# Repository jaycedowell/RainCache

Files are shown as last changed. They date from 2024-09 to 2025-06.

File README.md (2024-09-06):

# RainCache

## Parts List
 * Arduino Nano ESP32
 * Adafruit Universal USB / DC / Solar Lithium Ion/Polymer charger - bq24074
 * Adafruit MAX17048 LiPoly / LiIon Fuel Gauge and Battery Monitor
 * DFRobot Waterproof Ultrasonic Distance Sensor with Separate Probe (20~600cm)
 * Xain-USA: 3.7V 4400mAh, Li-ion rechargeable Battery Pack
 * Solar panel charger, 3W 6V
 * Norwesco 44405 1175 gallon Low Profile Underground Water Tank - x4
 * 3" PVC cap
 * 3" to 1 1/2" PVC reducer

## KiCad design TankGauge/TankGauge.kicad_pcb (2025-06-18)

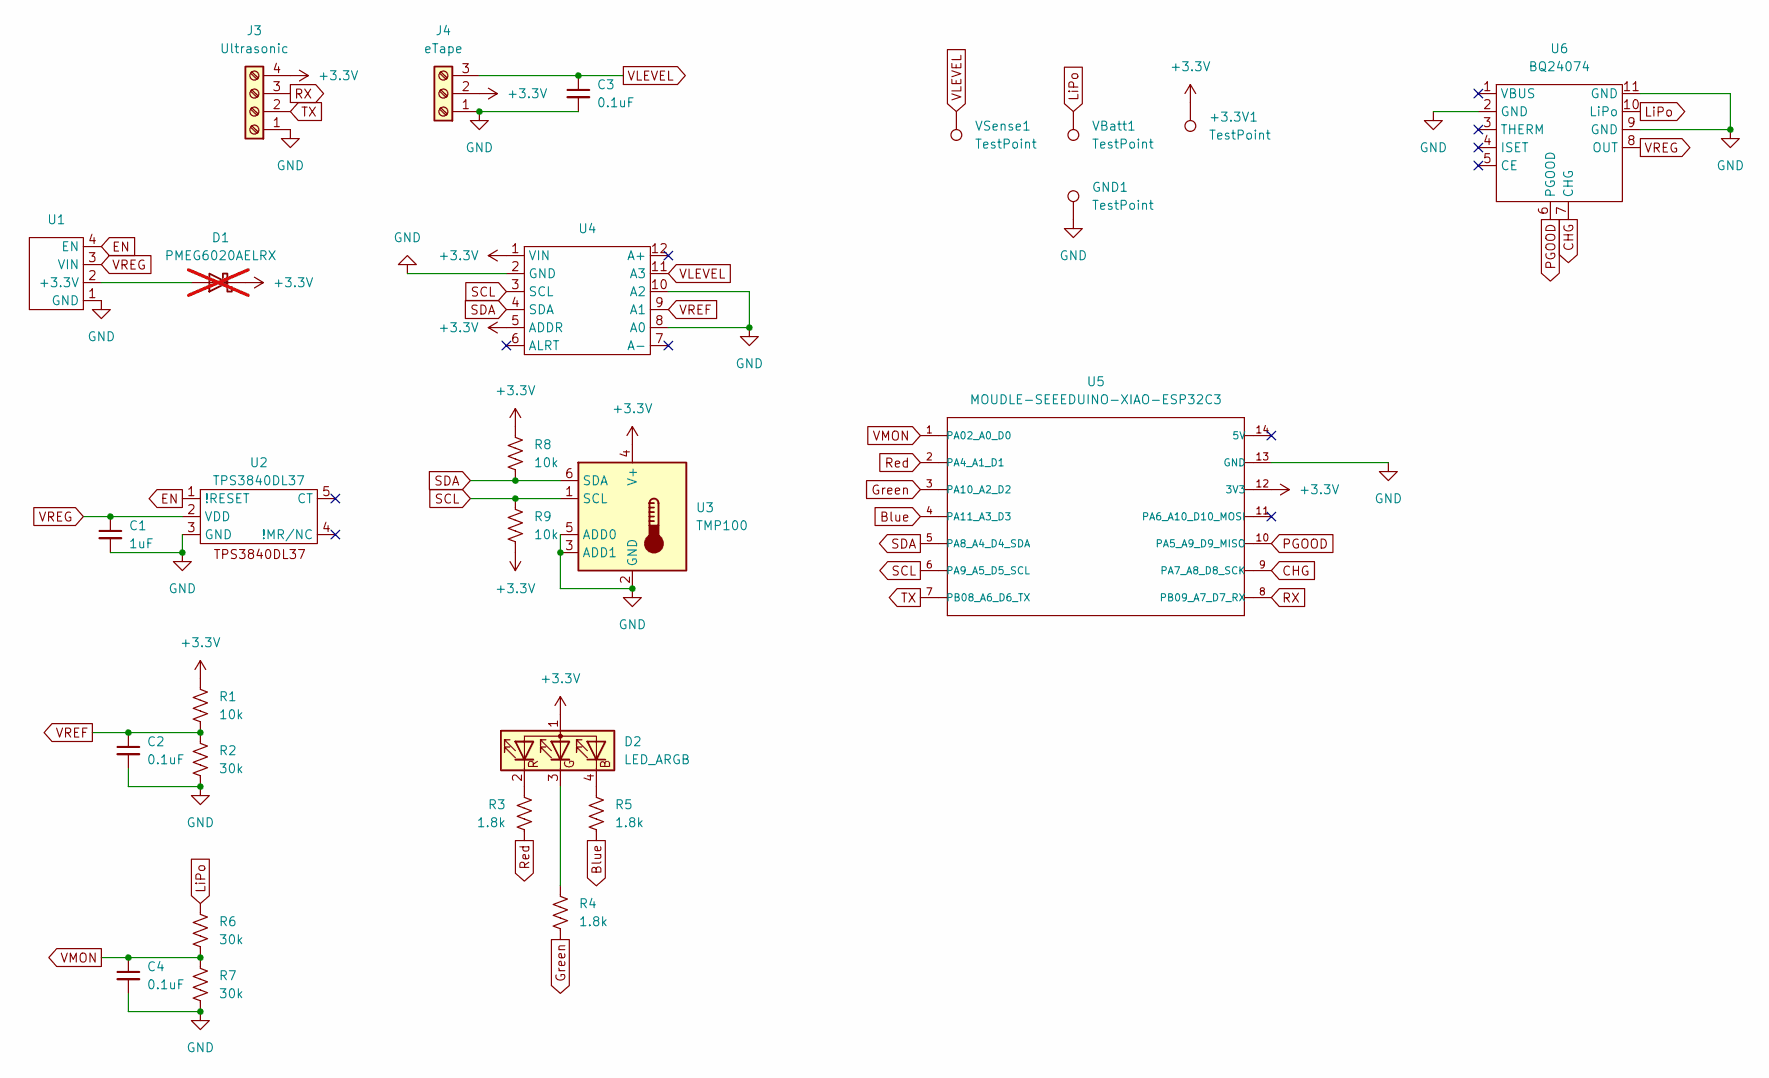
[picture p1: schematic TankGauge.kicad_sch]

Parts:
+3.3V1: TestPoint; TestPoint_Pad_D2.0mm
C1: 1uF; C_0805_2012Metric_Pad1.18x1.45mm_HandSolder
C2, C3, C4: 0.1uF; C_0805_2012Metric_Pad1.18x1.45mm_HandSolder
D1: PMEG6020AELRX; Nexperia_CFP3_SOD-123W; not fitted
D2: LED_ARGB; LED_Kingbright_AAA3528ESGCT
GND1: TestPoint; TestPoint_Pad_D2.0mm
J3: Ultrasonic; PinHeader_1x04_P2.54mm_Vertical
J4: eTape; PinHeader_1x03_P2.54mm_Vertical
R1, R8, R9: 10k; R_0805_2012Metric_Pad1.20x1.40mm_HandSolder
R2, R6, R7: 30k; R_0805_2012Metric_Pad1.20x1.40mm_HandSolder
R3, R4, R5: 1.8k; R_0805_2012Metric_Pad1.20x1.40mm_HandSolder
U1: TLV62569; TLV62569 Breakout Board
U2: TPS3840DL37; SOT-23-5_HandSoldering
U3: TMP100; SOT-23-6
U4: ADS1115 Breakout Board
U5: MOUDLE-SEEEDUINO-XIAO-ESP32C3; XIAO-ESP32C3
U6: BQ24074; PinHeader_1x11_P2.54mm_Vertical
VBatt1: TestPoint; TestPoint_Pad_D2.0mm
VSense1: TestPoint; TestPoint_Pad_D2.0mm

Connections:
+3.3V: +3.3V1.1, D1.1 (K), D2.1 (A), J3.4, J4.2, R1.1, R8.1, R9.2, U3.4 (V+), U4.1 (VIN), U4.5 (ADDR), U5.12 (3V3)
Blue: R5.2, U5.4 (PA11_A3_D3)
CHG: U5.9 (PA7_A8_D8_SCK), U6.7 (CHG)
EN: U1.4 (EN), U2.1 (!RESET)
GND: C1.2, C2.2, C3.2, C4.2, GND1.1, J3.1, J4.1, R2.2, R7.2, U1.1 (GND), U2.3 (GND), U3.2 (GND), U3.3 (ADD1), U3.5 (ADD0), U4.2 (GND), U4.8 (A0), U4.10 (A2), U5.13 (GND), U6.2 (GND), U6.9 (GND), U6.11 (GND)
Green: R4.2, U5.3 (PA10_A2_D2)
LiPo: R6.1, U6.10 (LiPo), VBatt1.1
unnamed: D1.2 (A), U1.2 (+3.3V)
unnamed: D2.4 (BK), R5.1
unnamed: D2.3 (GK), R4.1
unnamed: D2.2 (RK), R3.1
PGOOD: U5.10 (PA5_A9_D9_MISO), U6.6 (PGOOD)
RX: J3.3, U5.8 (PB09_A7_D7_RX)
Red: R3.2, U5.2 (PA4_A1_D1)
SCL: R9.1, U3.1 (SCL), U4.3 (SCL), U5.6 (PA9_A5_D5_SCL)
SDA: R8.2, U3.6 (SDA), U4.4 (SDA), U5.5 (PA8_A4_D4_SDA)
TX: J3.2, U5.7 (PB08_A6_D6_TX)
VLEVEL: C3.1, J4.3, U4.11 (A3), VSense1.1
VMON: C4.1, R6.2, R7.1, U5.1 (PA02_A0_D0)
VREF: C2.1, R1.2, R2.1, U4.9 (A1)
VREG: C1.1, U1.3 (VIN), U2.2 (VDD), U6.8 (OUT)

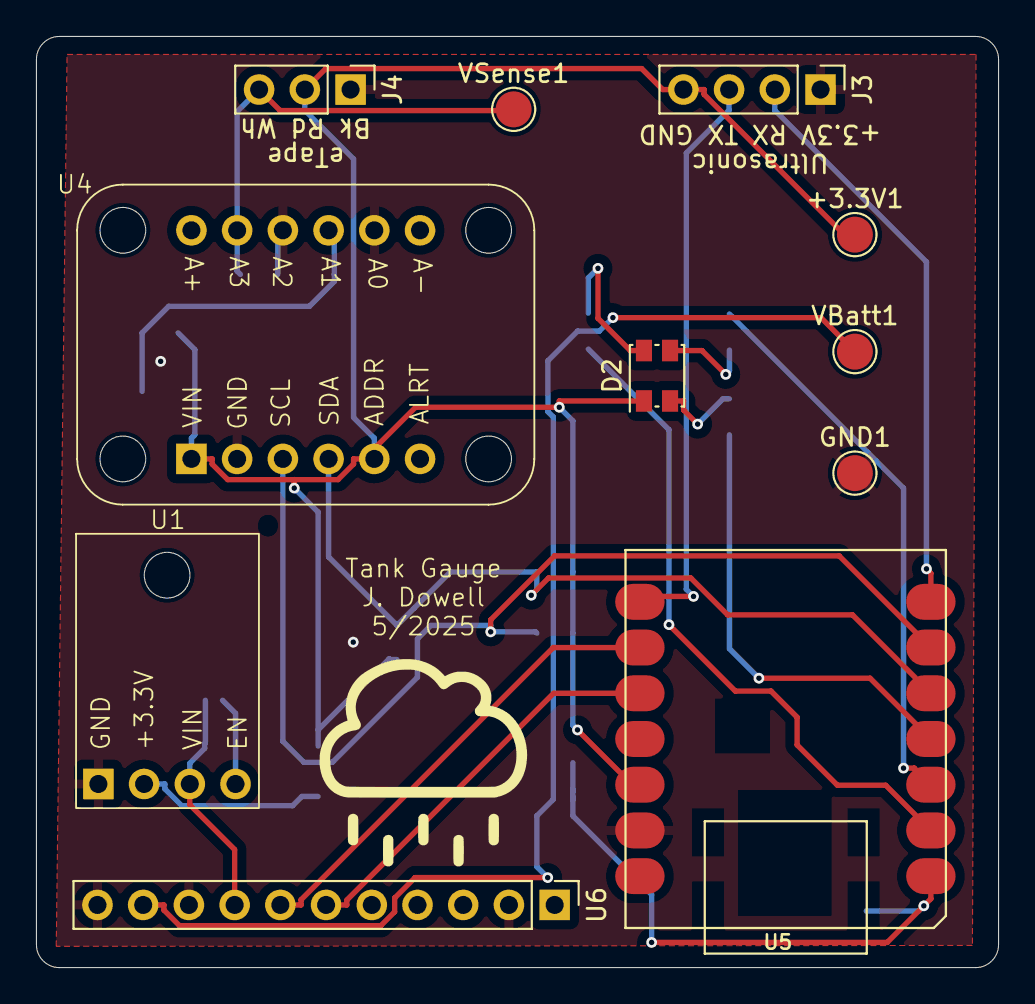
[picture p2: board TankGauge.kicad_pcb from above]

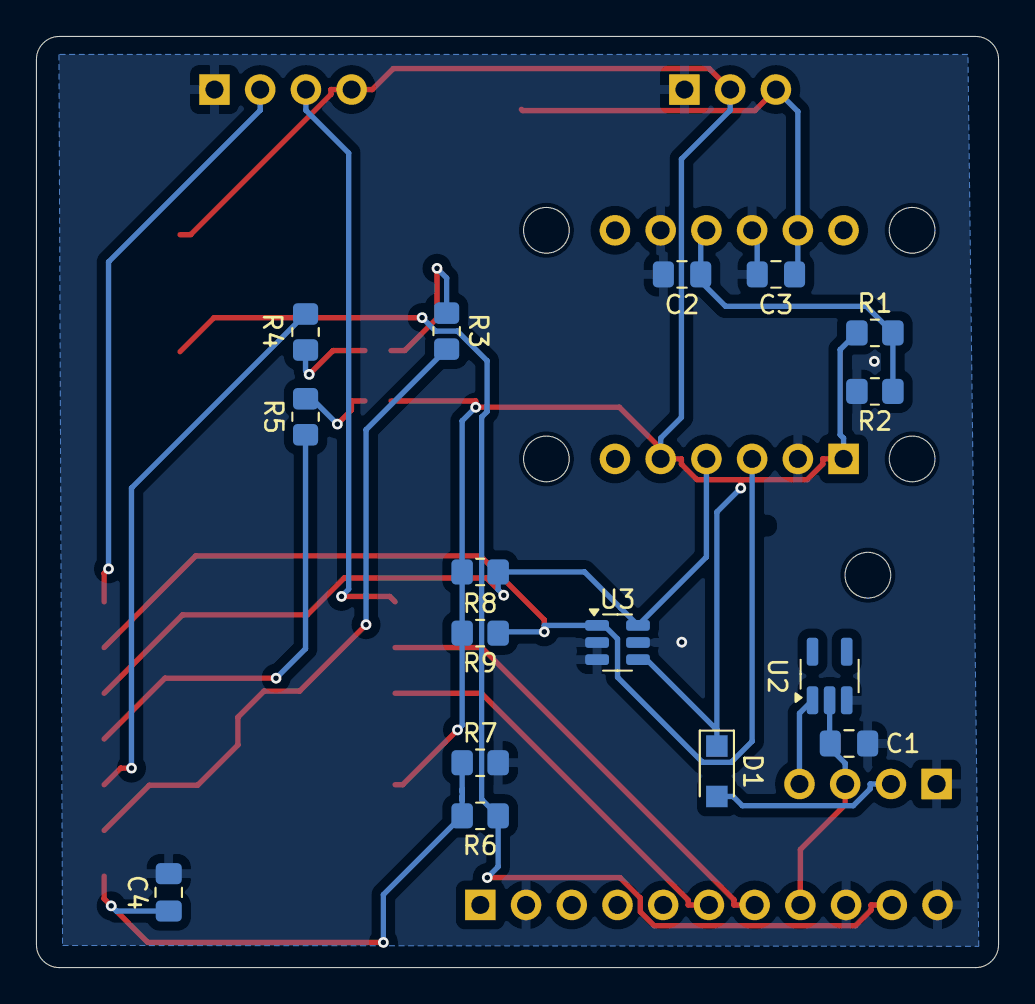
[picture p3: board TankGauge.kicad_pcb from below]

Board: 2 copper layers, 53.5 x 51.7 mm, 28 parts (16 on the bottom side), 21 nets.

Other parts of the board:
G1: LOGO; RainCache

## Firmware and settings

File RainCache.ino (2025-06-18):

#include <WiFi.h>
#include <ESP32Time.h>
#include <math.h>
#include <Wire.h>
#include "driver/temperature_sensor.h"
#include <Adafruit_ADS1X15.h>
#include "TMP100.h"

#include "WiFi_private.h"
/* WiFi_private.h includes:
    * ssid, pass - WiFi setup
    * staticIP, subnet - static IP address and network submask
    * gateway - gateway address
    * primaryDNS, secondaryDNS - DNS servers
*/

temperature_sensor_handle_t temp_sensor = NULL;
temperature_sensor_config_t temp_sensor_config = TEMPERATURE_SENSOR_CONFIG_DEFAULT(-10, 80);

WiFiServer server(80);

ESP32Time rtc(0);
unsigned long lastNTPSync = 0;

Adafruit_ADS1115 ads1115;
TMP100 tmp100;

byte icon_raw[] = {0, 0, 1, 0, 1, 0, 32, 32, 0, 0, 1, 0, 32, 0, 168, 16, 0, 0, 22, 0, 0, 0, 40, 0, 0, 0, 32, 0, 0, 0, 64, 0, 0, 0, 1, 0, 32, 0, 0, 0, 0, 0, 128, 16, 0, 0, 0, 0, 0, 0, 0, 0, 0, 0, 0, 0, 0, 0, 0, 0, 0, 0, 0, 0, 0, 0, 0, 0, 0, 0, 0, 0, 0, 0, 0, 0, 0, 0, 0, 0, 0, 0, 0, 0, 0, 0, 0, 0, 0, 0, 0, 0, 0, 0, 0, 0, 0, 0, 0, 0, 0, 0, 0, 0, 0, 0, 0, 0, 0, 0, 0, 0, 0, 0, 0, 0, 0, 0, 0, 0, 0, 0, 0, 0, 0, 0, 0, 0, 0, 0, 0, 0, 0, 0, 0, 0, 0, 0, 0, 0, 0, 0, 0, 0, 0, 0, 0, 0, 0, 0, 0, 0, 0, 0, 0, 0, 0, 0, 0, 0, 0, 0, 0, 0, 0, 0, 0, 0, 0, 0, 0, 0, 0, 0, 0, 0, 0, 0, 0, 0, 0, 0, 0, 0, 0, 0, 0, 0, 0, 0, 0, 0, 0, 0, 0, 0, 0, 0, 0, 0, 0, 0, 0, 0, 0, 0, 0, 0, 0, 0, 0, 0, 0, 0, 0, 0, 0, 0, 0, 0, 0, 0, 0, 0, 0, 0, 0, 0, 0, 0, 0, 0, 0, 0, 0, 0, 0, 0, 0, 0, 0, 0, 0, 0, 0, 0, 0, 0, 0, 0, 0, 0, 0, 0, 0, 0, 0, 0, 0, 0, 0, 0, 0, 0, 0, 0, 0, 0, 0, 0, 0, 0, 0, 0, 0, 0, 0, 0, 0, 0, 0, 0, 0, 0, 0, 0, 0, 0, 0, 0, 0, 0, 0, 0, 0, 0, 0, 0, 0, 0, 0, 0, 0, 0, 0, 0, 0, 0, 0, 0, 0, 0, 0, 0, 0, 0, 0, 0, 0, 0, 0, 0, 0, 0, 0, 0, 0, 0, 0, 0, 0, 0, 0, 0, 0, 0, 0, 0, 0, 0, 0, 0, 0, 0, 0, 0, 0, 0, 0, 0, 0, 0, 0, 0, 0, 0, 0, 0, 0, 0, 0, 0, 3, 0, 0, 77, 3, 0, 0, 77, 0, 0, 0, 0, 0, 0, 0, 0, 0, 0, 0, 0, 0, 0, 0, 0, 0, 0, 0, 0, 0, 0, 0, 0, 3, 0, 0, 77, 3, 0, 0, 77, 0, 0, 0, 0, 0, 0, 0, 0, 0, 0, 0, 0, 0, 0, 0, 0, 0, 0, 0, 0, 0, 0, 0, 0, 0, 0, 0, 0, 0, 0, 0, 0, 0, 0, 0, 0, 0, 0, 0, 0, 0, 0, 0, 0, 0, 0, 0, 0, 0, 0, 0, 0, 0, 0, 0, 0, 0, 0, 0, 0, 0, 0, 0, 0, 0, 0, 0, 0, 0, 0, 0, 0, 0, 0, 0, 0, 0, 0, 0, 0, 0, 0, 0, 0, 0, 0, 0, 0, 3, 0, 2, 248, 3, 0, 2, 249, 0, 0, 0, 0, 0, 0, 0, 0, 0, 0, 0, 0, 0, 0, 0, 0, 0, 0, 0, 0, 0, 0, 0, 0, 3, 0, 2, 248, 3, 0, 2, 249, 0, 0, 0, 0, 0, 0, 0, 0, 0, 0, 0, 0, 0, 0, 0, 0, 0, 0, 0, 0, 0, 0, 0, 0, 0, 0, 0, 0, 0, 0, 0, 0, 0, 0, 0, 0, 0, 0, 0, 0, 0, 0, 0, 0, 0, 0, 0, 0, 0, 0, 0, 0, 0, 0, 0, 0, 0, 0, 0, 0, 0, 0, 0, 0, 0, 0, 0, 0, 0, 0, 0, 0, 3, 0, 0, 77, 3, 0, 0, 77, 0, 0, 0, 0, 0, 0, 0, 0, 4, 1, 3, 255, 4, 1, 3, 255, 0, 0, 0, 0, 0, 0, 0, 0, 3, 0, 0, 77, 3, 0, 0, 77, 0, 0, 0, 0, 0, 0, 0, 0, 4, 1, 3, 255, 4, 1, 3, 255, 0, 0, 0, 0, 0, 0, 0, 0, 3, 0, 0, 77, 3, 0, 0, 77, 0, 0, 0, 0, 0, 0, 0, 0, 0, 0, 0, 0, 0, 0, 0, 0, 0, 0, 0, 0, 0, 0, 0, 0, 0, 0, 0, 0, 0, 0, 0, 0, 0, 0, 0, 0, 0, 0, 0, 0, 0, 0, 0, 0, 0, 0, 0, 0, 0, 0, 0, 0, 0, 0, 0, 0, 3, 0, 2, 248, 3, 0, 2, 249, 0, 0, 0, 0, 0, 0, 0, 0, 3, 0, 2, 248, 3, 0, 2, 248, 0, 0, 0, 0, 0, 0, 0, 0, 3, 0, 2, 248, 3, 0, 2, 249, 0, 0, 0, 0, 0, 0, 0, 0, 3, 0, 2, 248, 3, 0, 2, 248, 0, 0, 0, 0, 0, 0, 0, 0, 3, 0, 2, 248, 3, 0, 2, 249, 0, 0, 0, 0, 0, 0, 0, 0, 0, 0, 0, 0, 0, 0, 0, 0, 0, 0, 0, 0, 0, 0, 0, 0, 0, 0, 0, 0, 0, 0, 0, 0, 0, 0, 0, 0, 0, 0, 0, 0, 0, 0, 0, 0, 0, 0, 0, 0, 0, 0, 0, 0, 0, 0, 0, 0, 4, 1, 3, 255, 4, 1, 3, 255, 0, 0, 0, 0, 0, 0, 0, 0, 3, 0, 0, 77, 3, 0, 0, 77, 0, 0, 0, 0, 0, 0, 0, 0, 4, 1, 3, 255, 4, 1, 3, 255, 0, 0, 0, 0, 0, 0, 0, 0, 3, 0, 0, 77, 3, 0, 0, 77, 0, 0, 0, 0, 0, 0, 0, 0, 4, 1, 3, 255, 4, 1, 3, 255, 0, 0, 0, 0, 0, 0, 0, 0, 0, 0, 0, 0, 0, 0, 0, 0, 0, 0, 0, 0, 0, 0, 0, 0, 0, 0, 0, 0, 0, 0, 0, 0, 0, 0, 0, 0, 0, 0, 0, 0, 0, 0, 0, 0, 0, 0, 0, 0, 0, 0, 0, 0, 0, 0, 0, 0, 3, 0, 2, 248, 3, 0, 2, 248, 0, 0, 0, 0, 0, 0, 0, 0, 0, 0, 0, 0, 0, 0, 0, 0, 0, 0, 0, 0, 0, 0, 0, 0, 3, 0, 2, 248, 3, 0, 2, 248, 0, 0, 0, 0, 0, 0, 0, 0, 0, 0, 0, 0, 0, 0, 0, 0, 0, 0, 0, 0, 0, 0, 0, 0, 3, 0, 2, 248, 3, 0, 2, 248, 0, 0, 0, 0, 0, 0, 0, 0, 0, 0, 0, 0, 0, 0, 0, 0, 0, 0, 0, 0, 0, 0, 0, 0, 0, 0, 0, 0, 0, 0, 0, 0, 0, 0, 0, 0, 0, 0, 0, 0, 0, 0, 0, 0, 0, 0, 0, 0, 0, 0, 0, 0, 0, 0, 0, 0, 3, 0, 0, 77, 3, 0, 0, 77, 0, 0, 0, 0, 0, 0, 0, 0, 0, 0, 0, 0, 0, 0, 0, 0, 0, 0, 0, 0, 0, 0, 0, 0, 3, 0, 0, 77, 3, 0, 0, 77, 0, 0, 0, 0, 0, 0, 0, 0, 0, 0, 0, 0, 0, 0, 0, 0, 0, 0, 0, 0, 0, 0, 0, 0, 3, 0, 0, 77, 3, 0, 0, 77, 0, 0, 0, 0, 0, 0, 0, 0, 0, 0, 0, 0, 0, 0, 0, 0, 0, 0, 0, 0, 0, 0, 0, 0, 0, 0, 0, 0, 0, 0, 0, 0, 0, 0, 0, 0, 0, 0, 0, 0, 0, 0, 0, 7, 3, 0, 0, 76, 2, 0, 2, 119, 4, 0, 2, 127, 4, 0, 2, 127, 4, 0, 2, 127, 4, 0, 2, 127, 4, 0, 2, 127, 4, 0, 2, 127, 4, 0, 2, 127, 4, 0, 2, 127, 4, 0, 2, 127, 4, 0, 2, 127, 4, 0, 2, 127, 4, 0, 2, 127, 4, 0, 2, 127, 4, 0, 2, 127, 4, 0, 2, 127, 4, 0, 2, 127, 4, 0, 2, 127, 4, 0, 2, 127, 4, 0, 2, 127, 4, 0, 2, 127, 2, 0, 2, 119, 3, 0, 0, 76, 0, 0, 0, 7, 0, 0, 0, 0, 0, 0, 0, 0, 0, 0, 0, 0, 0, 0, 0, 0, 0, 0, 0, 0, 2, 0, 2, 90, 3, 0, 2, 232, 4, 1, 3, 255, 4, 1, 3, 255, 4, 1, 3, 255, 4, 1, 3, 255, 4, 1, 3, 255, 4, 1, 3, 255, 4, 1, 3, 255, 4, 1, 3, 255, 4, 1, 3, 255, 4, 1, 3, 255, 4, 1, 3, 255, 4, 1, 3, 255, 4, 1, 3, 255, 4, 1, 3, 255, 4, 1, 3, 255, 4, 1, 3, 255, 4, 1, 3, 255, 4, 1, 3, 255, 4, 1, 3, 255, 4, 1, 3, 255, 4, 1, 3, 255, 4, 1, 3, 255, 4, 1, 3, 255, 4, 1, 3, 255, 3, 0, 2, 232, 2, 0, 2, 90, 0, 0, 0, 0, 0, 0, 0, 0, 0, 0, 0, 0, 2, 0, 2, 114, 3, 1, 2, 254, 4, 1, 3, 255, 3, 0, 2, 205, 3, 0, 1, 138, 2, 0, 2, 127, 2, 0, 2, 127, 2, 0, 2, 127, 2, 0, 2, 127, 2, 0, 2, 127, 2, 0, 2, 127, 2, 0, 2, 127, 2, 0, 2, 127, 2, 0, 2, 127, 2, 0, 2, 127, 2, 0, 2, 127, 2, 0, 2, 127, 2, 0, 2, 127, 2, 0, 2, 127, 2, 0, 2, 127, 2, 0, 2, 127, 2, 0, 2, 127, 2, 0, 2, 127, 2, 0, 2, 127, 2, 0, 2, 127, 3, 0, 1, 138, 3, 0, 2, 205, 4, 1, 3, 255, 3, 1, 2, 254, 2, 0, 2, 114, 0, 0, 0, 0, 0, 0, 0, 48, 3, 0, 2, 251, 3, 0, 2, 252, 2, 0, 2, 103, 0, 0, 0, 0, 0, 0, 0, 0, 0, 0, 0, 0, 0, 0, 0, 0, 0, 0, 0, 0, 0, 0, 0, 0, 0, 0, 0, 0, 0, 0, 0, 0, 0, 0, 0, 0, 0, 0, 0, 0, 0, 0, 0, 0, 0, 0, 0, 0, 0, 0, 0, 0, 0, 0, 0, 0, 0, 0, 0, 0, 0, 0, 0, 0, 0, 0, 0, 0, 0, 0, 0, 0, 0, 0, 0, 0, 0, 0, 0, 0, 0, 0, 0, 0, 0, 0, 0, 0, 0, 0, 0, 0, 0, 0, 0, 0, 2, 0, 2, 102, 3, 0, 2, 252, 3, 0, 2, 251, 0, 0, 0, 48, 3, 0, 1, 164, 4, 1, 3, 255, 3, 0, 1, 141, 0, 0, 0, 0, 0, 0, 0, 0, 0, 0, 0, 0, 0, 0, 0, 0, 0, 0, 0, 0, 0, 0, 0, 0, 0, 0, 0, 0, 0, 0, 0, 0, 0, 0, 0, 0, 0, 0, 0, 0, 0, 0, 0, 0, 0, 0, 0, 0, 0, 0, 0, 0, 0, 0, 0, 0, 0, 0, 0, 0, 0, 0, 0, 0, 0, 0, 0, 0, 0, 0, 0, 0, 0, 0, 0, 0, 0, 0, 0, 0, 0, 0, 0, 0, 0, 0, 0, 0, 0, 0, 0, 0, 0, 0, 0, 0, 0, 0, 0, 0, 0, 0, 0, 0, 3, 0, 1, 141, 4, 1, 3, 255, 3, 0, 1, 164, 3, 0, 2, 230, 4, 1, 3, 255, 0, 0, 0, 36, 0, 0, 0, 0, 0, 0, 0, 0, 0, 0, 0, 0, 0, 0, 0, 0, 0, 0, 0, 0, 0, 0, 0, 0, 0, 0, 0, 0, 0, 0, 0, 0, 0, 0, 0, 0, 0, 0, 0, 0, 0, 0, 0, 0, 0, 0, 0, 0, 0, 0, 0, 0, 0, 0, 0, 0, 0, 0, 0, 0, 0, 0, 0, 0, 0, 0, 0, 0, 0, 0, 0, 0, 0, 0, 0, 0, 0, 0, 0, 0, 0, 0, 0, 0, 0, 0, 0, 0, 0, 0, 0, 0, 0, 0, 0, 0, 0, 0, 0, 0, 0, 0, 0, 0, 0, 0, 0, 35, 4, 1, 3, 255, 3, 0, 2, 230, 3, 0, 2, 251, 4, 1, 3, 255, 0, 0, 0, 4, 0, 0, 0, 0, 0, 0, 0, 0, 0, 0, 0, 0, 0, 0, 0, 0, 0, 0, 0, 0, 0, 0, 0, 0, 0, 0, 0, 0, 0, 0, 0, 0, 0, 0, 0, 0, 0, 0, 0, 0, 0, 0, 0, 0, 0, 0, 0, 0, 0, 0, 0, 0, 0, 0, 0, 0, 0, 0, 0, 0, 0, 0, 0, 0, 0, 0, 0, 0, 0, 0, 0, 0, 0, 0, 0, 0, 0, 0, 0, 0, 0, 0, 0, 0, 0, 0, 0, 0, 0, 0, 0, 0, 0, 0, 0, 0, 0, 0, 0, 0, 0, 0, 0, 0, 0, 0, 0, 3, 4, 1, 3, 255, 3, 1, 2, 252, 3, 0, 2, 229, 4, 1, 3, 255, 0, 0, 0, 37, 0, 0, 0, 0, 0, 0, 0, 0, 0, 0, 0, 0, 0, 0, 0, 0, 0, 0, 0, 0, 0, 0, 0, 0, 0, 0, 0, 0, 0, 0, 0, 0, 0, 0, 0, 0, 0, 0, 0, 0, 0, 0, 0, 0, 0, 0, 0, 0, 0, 0, 0, 0, 0, 0, 0, 0, 0, 0, 0, 0, 0, 0, 0, 0, 0, 0, 0, 0, 0, 0, 0, 0, 0, 0, 0, 0, 0, 0, 0, 0, 0, 0, 0, 0, 0, 0, 0, 0, 0, 0, 0, 0, 0, 0, 0, 0, 0, 0, 0, 0, 0, 0, 0, 0, 0, 0, 0, 35, 4, 1, 3, 255, 3, 0, 2, 231, 3, 0, 1, 163, 4, 1, 3, 255, 3, 0, 1, 143, 0, 0, 0, 0, 0, 0, 0, 0, 0, 0, 0, 0, 0, 0, 0, 0, 0, 0, 0, 0, 0, 0, 0, 0, 0, 0, 0, 0, 0, 0, 0, 0, 0, 0, 0, 0, 0, 0, 0, 0, 0, 0, 0, 0, 0, 0, 0, 0, 0, 0, 0, 0, 0, 0, 0, 0, 0, 0, 0, 0, 0, 0, 0, 0, 0, 0, 0, 0, 0, 0, 0, 0, 0, 0, 0, 0, 0, 0, 0, 0, 0, 0, 0, 0, 0, 0, 0, 0, 0, 0, 0, 0, 0, 0, 0, 0, 0, 0, 0, 0, 0, 0, 0, 0, 3, 0, 1, 141, 4, 1, 3, 255, 3, 0, 1, 165, 0, 0, 0, 47, 3, 0, 2, 251, 3, 0, 2, 253, 2, 0, 2, 104, 0, 0, 0, 0, 0, 0, 0, 0, 0, 0, 0, 0, 0, 0, 0, 0, 0, 0, 0, 0, 0, 0, 0, 0, 0, 0, 0, 0, 0, 0, 0, 0, 0, 0, 0, 0, 0, 0, 0, 0, 0, 0, 0, 0, 0, 0, 0, 0, 0, 0, 0, 0, 0, 0, 0, 0, 0, 0, 0, 0, 0, 0, 0, 0, 0, 0, 0, 0, 0, 0, 0, 0, 0, 0, 0, 0, 0, 0, 0, 0, 0, 0, 0, 0, 0, 0, 0, 0, 0, 0, 0, 0, 0, 0, 0, 0, 2, 0, 2, 103, 3, 0, 2, 252, 3, 0, 2, 251, 0, 0, 0, 49, 0, 0, 0, 0, 2, 0, 2, 112, 3, 1, 2, 254, 4, 1, 3, 255, 3, 0, 2, 207, 0, 0, 0, 8, 0, 0, 0, 0, 0, 0, 0, 0, 0, 0, 0, 0, 0, 0, 0, 0, 0, 0, 0, 0, 0, 0, 0, 0, 0, 0, 0, 0, 0, 0, 0, 0, 0, 0, 0, 0, 0, 0, 0, 0, 0, 0, 0, 0, 0, 0, 0, 0, 0, 0, 0, 0, 0, 0, 0, 0, 0, 0, 0, 0, 0, 0, 0, 0, 0, 0, 0, 0, 0, 0, 0, 0, 0, 0, 0, 0, 0, 0, 0, 8, 3, 0, 1, 139, 3, 0, 2, 205, 4, 1, 3, 255, 3, 1, 3, 254, 2, 0, 2, 115, 0, 0, 0, 0, 0, 0, 0, 0, 0, 0, 0, 0, 2, 0, 2, 88, 3, 1, 2, 254, 4, 1, 3, 255, 0, 0, 0, 2, 0, 0, 0, 0, 0, 0, 0, 0, 0, 0, 0, 0, 0, 0, 0, 0, 0, 0, 0, 0, 0, 0, 0, 0, 0, 0, 0, 0, 0, 0, 0, 0, 0, 0, 0, 0, 0, 0, 0, 0, 0, 0, 0, 0, 0, 0, 0, 0, 0, 0, 0, 0, 0, 0, 0, 0, 0, 0, 0, 0, 0, 0, 0, 0, 0, 0, 0, 0, 0, 0, 0, 0, 0, 0, 0, 0, 3, 0, 0, 68, 4, 1, 3, 255, 4, 1, 3, 255, 3, 0, 2, 232, 2, 0, 2, 91, 0, 0, 0, 0, 0, 0, 0, 0, 0, 0, 0, 0, 0, 0, 0, 0, 0, 0, 0, 0, 3, 0, 2, 237, 4, 1, 3, 255, 0, 0, 0, 21, 0, 0, 0, 0, 0, 0, 0, 0, 0, 0, 0, 0, 0, 0, 0, 0, 0, 0, 0, 0, 0, 0, 0, 0, 0, 0, 0, 0, 0, 0, 0, 0, 0, 0, 0, 0, 0, 0, 0, 0, 0, 0, 0, 0, 0, 0, 0, 0, 0, 0, 0, 0, 0, 0, 0, 0, 0, 0, 0, 0, 0, 0, 0, 0, 0, 0, 0, 0, 0, 0, 0, 0, 0, 0, 0, 3, 3, 0, 2, 194, 4, 1, 3, 255, 3, 0, 1, 144, 0, 0, 0, 7, 0, 0, 0, 0, 0, 0, 0, 0, 0, 0, 0, 0, 0, 0, 0, 0, 0, 0, 0, 0, 0, 0, 0, 0, 3, 0, 2, 194, 4, 1, 3, 255, 3, 0, 0, 77, 0, 0, 0, 0, 0, 0, 0, 0, 0, 0, 0, 0, 0, 0, 0, 0, 0, 0, 0, 0, 0, 0, 0, 0, 0, 0, 0, 0, 0, 0, 0, 0, 0, 0, 0, 0, 0, 0, 0, 0, 0, 0, 0, 0, 0, 0, 0, 0, 0, 0, 0, 38, 0, 0, 0, 14, 0, 0, 0, 0, 0, 0, 0, 0, 0, 0, 0, 0, 0, 0, 0, 14, 3, 0, 1, 168, 4, 1, 3, 255, 3, 0, 2, 229, 0, 0, 0, 15, 0, 0, 0, 0, 0, 0, 0, 0, 0, 0, 0, 0, 0, 0, 0, 0, 0, 0, 0, 0, 0, 0, 0, 0, 0, 0, 0, 0, 2, 0, 2, 120, 4, 1, 3, 255, 2, 0, 2, 175, 0, 0, 0, 0, 0, 0, 0, 0, 0, 0, 0, 0, 0, 0, 0, 0, 0, 0, 0, 0, 0, 0, 0, 0, 0, 0, 0, 0, 0, 0, 0, 0, 0, 0, 0, 0, 0, 0, 0, 0, 0, 0, 0, 0, 0, 0, 0, 0, 2, 0, 2, 175, 3, 0, 2, 238, 3, 0, 1, 159, 3, 0, 1, 130, 3, 0, 1, 159, 3, 0, 2, 236, 4, 1, 3, 255, 3, 0, 2, 241, 0, 0, 0, 56, 0, 0, 0, 0, 0, 0, 0, 0, 0, 0, 0, 0, 0, 0, 0, 0, 0, 0, 0, 0, 0, 0, 0, 0, 0, 0, 0, 0, 0, 0, 0, 0, 0, 0, 0, 23, 3, 0, 2, 245, 3, 0, 2, 254, 3, 0, 0, 70, 0, 0, 0, 0, 0, 0, 0, 0, 0, 0, 0, 0, 0, 0, 0, 0, 0, 0, 0, 0, 0, 0, 0, 0, 0, 0, 0, 0, 0, 0, 0, 0, 0, 0, 0, 0, 0, 0, 0, 0, 3, 0, 0, 69, 3, 0, 2, 254, 4, 1, 3, 255, 4, 1, 3, 255, 4, 1, 3, 255, 4, 1, 3, 255, 4, 1, 3, 255, 3, 0, 2, 192, 0, 0, 0, 40, 0, 0, 0, 0, 0, 0, 0, 0, 0, 0, 0, 0, 0, 0, 0, 0, 0, 0, 0, 0, 0, 0, 0, 0, 0, 0, 0, 0, 0, 0, 0, 0, 0, 0, 0, 0, 0, 0, 0, 0, 2, 0, 2, 119, 4, 1, 3, 255, 3, 0, 2, 237, 0, 0, 0, 50, 0, 0, 0, 0, 0, 0, 0, 0, 0, 0, 0, 0, 0, 0, 0, 0, 0, 0, 0, 0, 0, 0, 0, 0, 0, 0, 0, 0, 0, 0, 0, 0, 0, 0, 0, 50, 3, 0, 2, 236, 4, 1, 3, 255, 3, 0, 1, 140, 2, 0, 2, 105, 2, 0, 2, 125, 2, 0, 2, 105, 0, 0, 0, 44, 0, 0, 0, 0, 0, 0, 0, 0, 0, 0, 0, 0, 0, 0, 0, 0, 0, 0, 0, 0, 0, 0, 0, 0, 0, 0, 0, 0, 0, 0, 0, 0, 0, 0, 0, 0, 0, 0, 0, 0, 0, 0, 0, 0, 0, 0, 0, 0, 0, 0, 0, 2, 2, 0, 2, 173, 4, 1, 3, 255, 3, 0, 2, 245, 2, 0, 2, 115, 0, 0, 0, 9, 0, 0, 0, 0, 0, 0, 0, 0, 0, 0, 0, 0, 0, 0, 0, 0, 0, 0, 0, 8, 2, 0, 2, 114, 3, 0, 2, 244, 4, 1, 3, 255, 2, 0, 2, 174, 0, 0, 0, 2, 0, 0, 0, 0, 0, 0, 0, 0, 0, 0, 0, 0, 0, 0, 0, 0, 0, 0, 0, 0, 0, 0, 0, 0, 0, 0, 0, 0, 0, 0, 0, 0, 0, 0, 0, 0, 0, 0, 0, 0, 0, 0, 0, 0, 0, 0, 0, 0, 0, 0, 0, 0, 0, 0, 0, 0, 0, 0, 0, 0, 0, 0, 0, 0, 0, 0, 0, 0, 0, 0, 0, 5, 3, 0, 1, 154, 4, 1, 3, 254, 4, 1, 3, 255, 3, 0, 2, 239, 2, 0, 2, 172, 3, 0, 1, 135, 3, 0, 1, 134, 2, 0, 2, 171, 3, 0, 2, 238, 4, 1, 3, 255, 4, 1, 3, 254, 3, 0, 1, 155, 0, 0, 0, 5, 0, 0, 0, 0, 0, 0, 0, 0, 0, 0, 0, 0, 0, 0, 0, 0, 0, 0, 0, 0, 0, 0, 0, 0, 0, 0, 0, 0, 0, 0, 0, 0, 0, 0, 0, 0, 0, 0, 0, 0, 0, 0, 0, 0, 0, 0, 0, 0, 0, 0, 0, 0, 0, 0, 0, 0, 0, 0, 0, 0, 0, 0, 0, 0, 0, 0, 0, 0, 0, 0, 0, 0, 0, 0, 0, 0, 0, 0, 0, 0, 3, 0, 0, 71, 3, 0, 2, 198, 3, 1, 2, 254, 4, 1, 3, 255, 4, 1, 3, 255, 4, 1, 3, 255, 4, 1, 3, 255, 4, 1, 3, 254, 3, 0, 2, 200, 3, 0, 0, 72, 0, 0, 0, 0, 0, 0, 0, 0, 0, 0, 0, 0, 0, 0, 0, 0, 0, 0, 0, 0, 0, 0, 0, 0, 0, 0, 0, 0, 0, 0, 0, 0, 0, 0, 0, 0, 0, 0, 0, 0, 0, 0, 0, 0, 0, 0, 0, 0, 0, 0, 0, 0, 0, 0, 0, 0, 0, 0, 0, 0, 0, 0, 0, 0, 0, 0, 0, 0, 0, 0, 0, 0, 0, 0, 0, 0, 0, 0, 0, 0, 0, 0, 0, 0, 0, 0, 0, 0, 0, 0, 0, 0, 0, 0, 0, 0, 0, 0, 0, 34, 2, 0, 2, 92, 2, 0, 2, 120, 2, 0, 2, 121, 2, 0, 2, 93, 0, 0, 0, 35, 0, 0, 0, 0, 0, 0, 0, 0, 0, 0, 0, 0, 0, 0, 0, 0, 0, 0, 0, 0, 0, 0, 0, 0, 0, 0, 0, 0, 0, 0, 0, 0, 0, 0, 0, 0, 0, 0, 0, 0, 0, 0, 0, 0, 0, 0, 0, 0, 0, 0, 0, 0, 0, 0, 0, 0, 0, 0, 0, 0, 0, 0, 0, 0, 0, 0, 0, 0, 0, 0, 0, 0, 0, 0, 0, 0, 0, 0, 0, 0, 0, 0, 0, 0, 0, 0, 0, 0, 0, 0, 0, 0, 0, 0, 0, 0, 0, 0, 0, 0, 0, 0, 0, 0, 0, 0, 0, 0, 0, 0, 0, 0, 0, 0, 0, 0, 0, 0, 0, 0, 0, 0, 0, 0, 0, 0, 0, 0, 0, 0, 0, 0, 0, 0, 0, 0, 0, 0, 0, 0, 0, 0, 0, 0, 0, 0, 0, 0, 0, 0, 0, 0, 0, 0, 0, 0, 0, 0, 0, 0, 0, 0, 0, 0, 0, 0, 0, 0, 0, 0, 0, 0, 0, 0, 0, 0, 0, 0, 0, 0, 0, 0, 0, 0, 0, 0, 0, 0, 0, 0, 0, 0, 0, 0, 0, 0, 0, 0, 0, 0, 0, 0, 0, 0, 0, 0, 0, 0, 0, 0, 0, 0, 0, 0, 0, 0, 0, 0, 0, 0, 0, 0, 0, 0, 0, 0, 0, 0, 0, 0, 0, 0, 0, 0, 0, 0, 0, 0, 0, 0, 0, 0, 0, 0, 0, 0, 0, 0, 0, 0, 0, 0, 0, 0, 0, 0, 0, 0, 0, 0, 0, 0, 0, 0, 0, 0, 0, 0, 0, 0, 0, 0, 0, 0, 0, 0, 0, 0, 0, 0, 0, 0, 0, 0, 0, 0, 0, 0, 0, 0, 0, 0, 0, 0, 0, 0, 0, 0, 0, 0, 0, 0, 0, 0, 0, 0, 0, 0, 0, 0, 0, 0, 0, 0, 0, 0, 0, 0, 0, 0, 0, 0, 0, 0, 255, 255, 255, 255, 255, 255, 255, 255, 255, 231, 231, 255, 255, 231, 231, 255, 254, 102, 102, 127, 254, 102, 102, 127, 254, 102, 102, 127, 254, 126, 126, 127, 254, 126, 126, 127, 224, 0, 0, 7, 192, 0, 0, 3, 128, 0, 0, 1, 15, 255, 255, 240, 31, 255, 255, 248, 31, 255, 255, 248, 31, 255, 255, 248, 31, 255, 255, 248, 31, 255, 255, 248, 15, 255, 255, 240, 131, 255, 255, 129, 195, 255, 255, 131, 227, 255, 255, 7, 227, 255, 206, 15, 227, 255, 192, 31, 225, 255, 128, 63, 240, 255, 0, 255, 240, 60, 15, 255, 248, 0, 31, 255, 254, 0, 127, 255, 255, 129, 255, 255, 255, 255, 255, 255, 255, 255, 255, 255};

// Approximate LiPo state-of-charge as a function voltage in steps of 5%
float lipo_soc_volt[] = {4.2 , 4.15, 4.11, 4.08, 4.02,  // 100, 95, 90, 85, 80
                         3.98, 3.95, 3.91, 3.87, 3.85,  //  75, 70, 65, 60, 55
                         3.84, 3.82, 3.8 , 3.79, 3.77,  //  50, 45, 40, 35, 30
                         3.75, 3.73, 3.71, 3.69, 3.61,  //  25, 20, 15, 10,  5
                         3.27};                         //   0

#define LED_RED D1
#define LED_GREEN D2
#define LED_BLUE D3

#define PGOOD_PIN D9
#define CHRG_PIN D8

#define VBATT_PIN A0

void setup() {
  // Set the pins for the on-board RGB LED to output
  pinMode(LED_RED, OUTPUT);
  pinMode(LED_GREEN, OUTPUT);
  pinMode(LED_BLUE, OUTPUT);

  pinMode(PGOOD_PIN, INPUT);
  pinMode(CHRG_PIN, INPUT);

  pinMode(VBATT_PIN, INPUT);
  
  // Enable the SoC temperature sensor
  temperature_sensor_install(&temp_sensor_config, &temp_sensor);
  temperature_sensor_enable(temp_sensor);
  delay(10); 

  // Start the TMP100 sensor
  tmp100.begin();
  tmp100.setResolution(10);
  delay(10);  

  // Start the ADC
  ads1115.begin(0x49);
  ads1115.setGain(GAIN_ONE); 
  delay(10);

  // Set the static IP
  WiFi.config(staticIP, gateway, subnet, primaryDNS, secondaryDNS);
  delay(10);

  // Set the last NTP sync time to zero
  lastNTPSync = 0;

  led_off();
}
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

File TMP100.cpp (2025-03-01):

#include "Arduino.h"
#include "TMP100.h"

TMP100::TMP100(void) {}
TMP100::~TMP100(void) {}

bool TMP100::begin(TwoWire *wire) {
  if( i2c_dev ) {
    delete i2c_dev;
  }

  i2c_dev = wire;
  i2c_dev->beginTransmission(TMP100_I2CADDR_DEFAULT);
  byte error = i2c_dev->endTransmission();

  if( error != 0 ) {
    return false;
  }

  return true;
}

bool TMP100::isDeviceReady() {
  if( !i2c_dev || _delay == 0 ) {
    return false;
  }

  i2c_dev->beginTransmission(TMP100_I2CADDR_DEFAULT);
  byte error = i2c_dev->endTransmission();
  return (error == 0);
}

bool TMP100::setResolution(int nbit) {
  if( !i2c_dev || nbit < 9 || nbit > 12 ) {
    return false;
  }

  switch(nbit) {
    case 9:  _delay = TMP100_CONV_DELAY_9BIT; break;
    case 10: _delay = TMP100_CONV_DELAY_10BIT; break;
    case 11: _delay = TMP100_CONV_DELAY_11BIT; break;
    default: _delay = TMP100_CONV_DELAY_12BIT;
  }
  
  i2c_dev->beginTransmission(TMP100_I2CADDR_DEFAULT);
  i2c_dev->write(TMP100_CONFIG_REG);
  i2c_dev->write(((unsigned char) (nbit - 9)) << 5);
  byte error = i2c_dev->endTransmission();

  return (error == 0);
}

int TMP100::getResolution() {
  if( !i2c_dev || _delay == 0 ) {
    return 0;
  }

  switch(_delay) {
    case TMP100_CONV_DELAY_9BIT: return 9;
    case TMP100_CONV_DELAY_10BIT: return 10;
    case TMP100_CONV_DELAY_11BIT: return 11;
    case TMP100_CONV_DELAY_12BIT: return 12;
    default: return 0;
  }

  return 0;
}

float TMP100::getTemp() {
  if( !i2c_dev || _delay == 0 ) {
    return -99.0;
  }
  
  i2c_dev->beginTransmission(TMP100_I2CADDR_DEFAULT);
  i2c_dev->write(TMP100_READ_REG);
  byte error = i2c_dev->endTransmission();

  if( error != 0 ) {
    return -99.0;
  }

  unsigned long startTime = millis();
  while( i2c_dev->requestFrom(TMP100_I2CADDR_DEFAULT, 2) != 2 ) {
    if( (millis() - startTime) > (_delay + 10) ) {
      return -99.0;
    }
    delay(5);
  }

  int16_t buffer = 0;
  buffer |= (i2c_dev->read() << 8);
  buffer |= i2c_dev->read();
  float temp = buffer / 16.0 * 0.0625;

  return temp;
}

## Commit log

2025-03-01 Add support for the new PCB that includes a TMP100 temperature sensor. Plus, many cleanups to improve stability.
    [RainCache.ino, TMP100.cpp, TMP100.h]
2025-03-01 Add PCB schematics.
    [TankGauge.kicad_pcb, TankGauge.kicad_sch]
2025-03-01 Added a voltage divider to address #1.
    [TankGauge.kicad_pcb, TankGauge.kicad_sch]
2025-03-02 Fixed an infinite loop when there is a problem reading from the distance sensor. Also, better failure diagnostics and periodic time syncs.
    [RainCache.ino]
2025-06-14 Use the eTape and a ADS1115 for better results.
    [TankGauge.kicad_pcb, TankGauge.kicad_sch]
2025-06-16 Use more macros and add a readout of the reference voltage.
2025-06-16 DNP D1 since it has too much voltage drop across it.
    [TankGauge.kicad_sch]
2025-06-18 Change voltage divider ratio on the battery monitor.
    [TankGauge.kicad_pcb, TankGauge.kicad_sch]
2025-06-18 Update for new battery voltage divider and fix a few typos.
    [RainCache.ino]
